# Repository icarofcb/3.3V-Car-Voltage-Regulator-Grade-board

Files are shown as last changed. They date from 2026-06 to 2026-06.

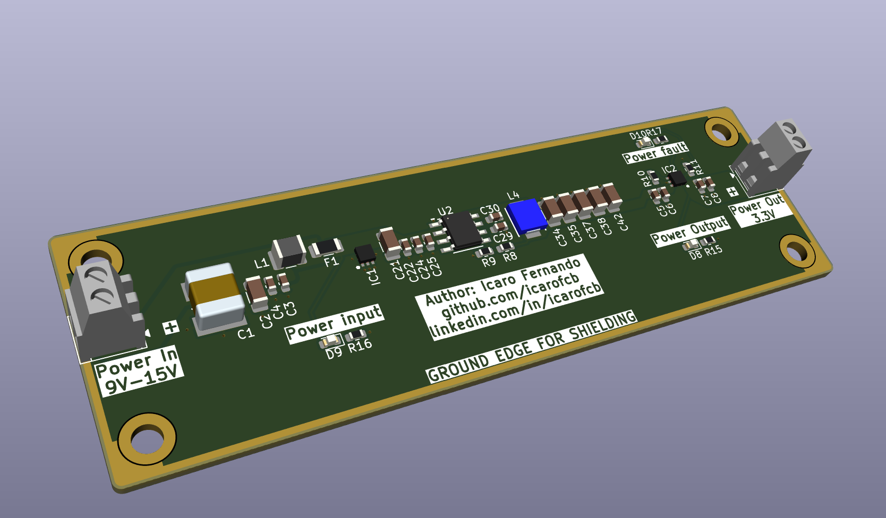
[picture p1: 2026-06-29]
manufacture files/BOARD-1.png

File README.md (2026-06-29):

# 3V3-REGULATOR — Design Notes

**Project:** Automotive-grade 9 V–15 V to 3.3 V / 500 mA power supply
**Author:** Icaro (github.com/icarofcb)
**Tool:** KiCad 10.0.4 · 2-layer PCB
**Rev:** 1 · 2026-06-28

---

## 1. Overview

This board converts an unregulated automotive DC bus (9 V–15 V) into a clean, regulated **3.3 V rail at up to 500 mA**, with the input, the converter, and the load protected end to end. The signal path is:

```
J2 (9–15 V) → [Protected Input: fuse + ferrite + flat-clamp TVS + bulk caps]
            → [Synchronous Buck: LMR33630BDDA @ 1.4 MHz]
            → [Smart Fuse: TPS25200 eFuse, current limit + OV clamp + fault flag]
            → J9 (3.3 V protected output)
```

Visual diagnostics (power-good and fault LEDs) and four mounting holes are provided for integration and bring-up.

---

## 2. Electrical Specifications

| Parameter | Specification | As-designed |
|---|---|---|
| Input voltage | 9 V – 15 V DC | 9 V – 15 V (LMR33630: 3.8 V–36 V) |
| Output voltage | 3.3 V DC | 3.315 V (FB divider 100 k / 43.2 k) |
| Output current | 500 mA max | eFuse limit ≈ 1.43 A typ (margin) |
| Output power | 1.65 W | 1.65 W |
| Topology | Candidate's choice | **Synchronous buck** (justified §3) |
| Switching frequency | — | 1.4 MHz (LMR33630**B**DDA) |
| Estimated efficiency | State | **≈ 86–88 %** @ 12 V, 0.5 A (§5) |
| Target ripple | State | **< 20 mV pk-pk** (est. ~5 mV, §6) |

---

## 3. Topology Selection & Justification

**Chosen: synchronous step-down (buck) converter.**

A linear regulator (LDO) was rejected on thermal grounds. Dropping 12 V → 3.3 V at 0.5 A in a linear pass element dissipates `(12 − 3.3) × 0.5 = 4.35 W`, and at the 15 V corner `(15 − 3.3) × 0.5 = 5.85 W`. That is an efficiency of only 22–28 % and several watts to remove from a small 2-layer board with no dedicated copper plane — not viable.

A synchronous buck reaches ~85–90 % at this operating point, dissipating only a few hundred mW. The **LMR33630BDDA** was selected because it:

- Covers the full input range with wide margin (3.8 V–36 V vs. 9–15 V), tolerating load-dump ride-through above 15 V.
- Integrates both MOSFETs (synchronous), removing the external catch diode and its loss.
- Switches at **1.4 MHz**, which shrinks the inductor (2.2 µH) and output caps and places the switching fundamental above the AM band, easing conducted-EMI compliance.
- Is marketed as an "ultra-low EMI" SIMPLE SWITCHER in an SO PowerPAD package with low parasitic loop inductance.
- Has an internally compensated, peak-current-mode loop — minimal external part count, robust across line/load.

---

## 4. Functional Block Description

### 4.1 Protected Input Stage

| Ref | Part | Role |
|---|---|---|
| F1 | SF-1206HHA1000R-2 | Board input fuse — hard-fault / short protection. Note on schematic: can be replaced by an automotive blade fuse. |
| L1 | Ferrite 26 Ω @ 100 MHz, 10 A | Series element of the input EMI filter (conducted-emissions / di-dt damping). |
| IC1 | TVS1800DRVR | Flat-clamp surge protection (load-dump / ISO 7637-style transients), 18 V standoff. |
| C1 | 47 µF | Bulk input hold-up. |
| C2, C21 | 10 µF 50 V | Buck input decoupling (high-frequency hot-loop caps). |
| C3, C4, C22, C24 | 0.1 µF | Local HF bypass. |
| C29 | 1 µF | Protected-rail decoupling. |

The fuse, ferrite, and bulk/HF caps form a **pi (C–L–C) input filter**: the ferrite blocks the switcher's di/dt from the harness while the caps supply the pulsed input current locally. The TVS1800 shunts surge energy and clamps flat, with an 18 V standoff that sits comfortably above the 15 V input corner.

### 4.2 Buck Regulator

| Ref | Part | Role |
|---|---|---|
| U2 | LMR33630BDDA | 1.4 MHz synchronous buck, 3.8–36 V in, 3 A. |
| L4 | 2.2 µH | Power inductor. |
| R8 / R9 | 100 k / 43.2 k | Feedback divider → V_OUT = 1.0 V × (1 + 100/43.2) = **3.315 V**. |
| C30 | 0.1 µF | Bootstrap (BOOT–SW). |
| C5 / C7 | 1 µF | VCC / local decoupling. |
| C34, C35, C37, C38, C42 | 10 µF 50 V | Output capacitor bank (3.3 V rail). |

The 1.0 V internal reference and the 100 k / 43.2 k divider set 3.315 V (+0.5 %, within tolerance). The output bank is deliberately conservative for low ripple and good transient response; effective capacitance after DC-bias derating is well below the 50 µF nominal but still ample for this load.

### 4.3 Output Smart Fuse (eFuse)

| Ref | Part | Role |
|---|---|---|
| IC2 | TPS25200DRVR | eFuse: adjustable current limit, OV clamp, OVLO, thermal, reverse blocking, fault flag. |
| R11 | 68 k | R_ILIM → current-limit threshold. |
| D8, D9 (blue) | Power-good indicators | Lit on healthy 3.3 V. |
| D10 (red) | Fault indicator | Driven by FAULT (open-drain). |
| R15, R17 (220 Ω), R16 (1 k) | LED / pull-up resistors | |
| J9 | 282834-2 | Protected 3.3 V output. |

`R_ILIM = 68 kΩ` sets a current-limit threshold of **≈ 1.43 A typ** (≈ 1.30 A min / 1.55 A max over tolerance from the datasheet I_OS equations). That sits comfortably above the 500 mA spec and even above a 1 A transient peak, while still cutting off hard on a downstream short. The TPS25200 also provides an output OV **clamp at ~5.4 V** and **OVLO shutoff at 7.6 V V_IN**, so a failed buck high-side FET dumping the raw input onto the 3.3 V rail is disconnected from the load rather than passed through. The open-drain FAULT asserts on over-current, over-temperature, or over-voltage and drives the red LED — no microcontroller required.

---

## 5. Efficiency Estimate

At 12 V → 3.3 V, 0.5 A, the LMR33630 (1.4 MHz variant) operates around **87 %** per its characteristic curves. The series eFuse adds `60 mΩ × 0.5 A = 30 mV` drop → `~0.9 %` loss. Net **≈ 86 %** at nominal.

Trend across the input range (switching loss scales with V_IN):

| V_IN | Est. converter η | Net (incl. eFuse) |
|---|---|---|
| 9 V | ~89 % | ~88 % |
| 12 V | ~87 % | ~86 % |
| 15 V | ~85 % | ~84 % |

Total dissipation at the worst corner is on the order of a few hundred mW, spread across U2's PowerPAD and L4 — manageable on 2 layers with a stitched ground pour and a thermal-via array under the IC.

---

## 6. Ripple Budget

**Inductor ripple current** (`ΔI_L = V_OUT·(V_IN−V_OUT)/(V_IN·L·f_sw)`):

- 12 V: `3.3 × 8.7 / (12 × 2.2µ × 1.4M) ≈ 0.78 A` pk-pk
- 15 V (worst): `≈ 0.84 A` pk-pk
- Peak inductor current at 0.5 A load: `0.5 + 0.42 ≈ 0.92 A` — far below L4 / U2 limits.

**Output voltage ripple** (ceramic bank, ESR negligible, `ΔV ≈ ΔI_L/(8·f_sw·C_OUT)`):

- With ~40 µF effective: `0.84 / (8 × 1.4M × 40µ) ≈ 2 mV` pk-pk.

**Target: < 20 mV pk-pk**; estimated **~5 mV** including ESL/ESR margin. Input ripple is held down by C1/C2/C21 plus the L1 ferrite (pi filter).

---

## 7. Automotive Best Practices

**Protection (layered):**
1. Input hard-fault / short → F1 (replaceable by a blade fuse, coordinated with the vehicle supply).
2. Surge / load-dump transients → TVS1800 flat clamp (18 V standoff, clamps surge below ~25 V — well under the LMR33630 36 V abs-max and the 50 V cap rating).
3. Output over-current / short / OV / reverse → TPS25200 eFuse with auto-recovery and fault flag.
4. Visual go/no-go → power-good (blue) and fault (red) LEDs.

**EMI / EMC:**
- 1.4 MHz fundamental keeps key harmonics out of the AM band.
- Pi input filter (C–ferrite–C) attenuates conducted emissions on the harness.
- Tight switching hot loop and small SW-node copper minimize radiated emissions.
- TVS + bulk caps address surge immunity (IEC 61000-4-5 class) and EFT/ESD on the input.
- Exposed gold perimeter ring bonds PCB ground to the aluminum enclosure (360° chassis bond), extending the shield to the case.

**Power / Signal Integrity:**
- Output cap bank close to the load connector for low rail impedance and good step-load response.
- Feedback divider routed away from the SW node; FB tap taken at the point of regulation.
- Unbroken bottom-layer ground plane as the reference and lowest-impedance return for every net.

**DFM / DFT / DFA:**
- DFM: assembly-friendly 1206/0603 passives, standard footprints, thermal-via arrays under U2 and IC2, generous clearances for a 2-layer process.
- DFT: test points on V_IN, 3.3 V, FAULT, and GND; FAULT net brought out; LEDs give instant powered diagnostics; output on a keyed connector for in-line current measurement.
- DFA: polarized 282834-2 connectors (no reverse mating), consistent passive orientation, four mounting holes (H1–H4) for mechanical fixturing and vibration robustness.

---

## 8. 2-Layer PCB Layout Strategy

The stackup is deliberately simple and EMC-driven: **the top layer carries all signals and power; the bottom layer is an unbroken ground plane.** On a 2-layer board this is the single biggest lever for EMC and integrity — every trace on top runs over continuous reference copper, so each signal's return current flows in the image directly beneath it, giving the smallest possible loop area and a clean, low-impedance return for every net.

- **Solid ground plane (bottom):** the entire second layer is ground, with no splits or cutouts. Nothing signal or power is routed on the bottom, because any trace there would slot the plane and force return current to detour around it (added loop area → radiated emissions and ground bounce).
- **Input hot loop** (C2/C21 → VIN → GND) kept physically tiny on top — it carries the highest di/dt — with its ground return dropped straight into the plane through vias at the cap pads.
- **SW node** copper minimized in area (radiator) but wide enough for current; inductor placed immediately at SW.
- **Returns / stitching:** a ground via at every ground pad ties each device to the plane with minimal inductance; vias along the high-current return path keep impedance low.
- **Chassis-bond shield ring:** an exposed (soldermask-free), gold-finished (ENIG) ground ring runs around the board perimeter and is via-stitched to the bottom plane, so it bonds PCB ground to the aluminum enclosure around the full edge. Gold keeps the contact low-resistance and corrosion-free under compression and vibration (bare copper would oxidize into an unreliable joint). The 360° bond extends the Faraday shield onto the case, improving radiated emissions and immunity, and gives a short chassis return path for ESD/surge.
- **Thermal:** U2 PowerPAD and IC2 EP drop into the bottom ground copper through via arrays, using the full plane as the heat-spreader.
- **Output caps** hugging the inductor output and the eFuse input; protected-rail caps near J9.
- **Sensitive nets** (FB, ILIM) kept short over solid ground, away from SW and the inductor field.
- **Input protection** (F1, L1, TVS1800) placed at the connector edge so transient energy is shunted before it propagates onto the board.

---

## 9. Component Selection Notes

- **Decoupling / bulk MLCCs:** specified as Murata **GCM** series (AEC-Q200, X7R, −55…+125 °C). For positions in 0805 and larger, or anywhere board flex/vibration is a concern, the **GCJ** soft-termination equivalents are the preferred upgrade (conductive-polymer layer that absorbs board-bending stress and prevents flex cracks).
- **10 µF / 50 V / 1206:** only available as **X7T** in this size/voltage (e.g. GCM31CD71H106KE36L) — note the wider temperature/DC-bias characteristic vs. X7R and the heavy DC-bias derating on the 9–15 V input cap (C2).
- **Voltage derating:** 50 V ceramics on a 3.3 V rail and on the 12 V bus keep stress well inside ECSS/IPC-style derating; the 1 µF/0603 parts are 25 V (fine on 3.3 V/5 V nodes, re-evaluate if any sits on the raw 9–15 V bus).
- **eFuse R_ILIM = 68 kΩ** verified against the TPS25200 datasheet I_OS equations (not just the table): min ≈ 1.30 A stays clear of the load; max ≈ 1.55 A gives a defined cut-off.

---

## 10. Submitted Files

| File | Description |
|---|---|
| `3v3-regulator.kicad_pro` | KiCad project |
| `3v3-regulator.kicad_sch` | Schematic |
| `3v3-regulator.kicad_pcb` | 2-layer PCB layout |
| `README` / Design Notes | This document |

## 11. Extra Files

The `manufacture files` directory holds the full output set: design notes, fabrication/manufacturing files, and the schematic export. Gerbers and the schematic source are also available in the `gerber/` and `Schematic/` directories.

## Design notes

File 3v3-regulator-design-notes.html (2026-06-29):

Design Notes · Rev 1 · 2026-06-28

# 3V3-Regulator

Automotive-grade 9 V–15 V → 3.3 V / 500 mA power supply. Synchronous buck with a fully protected input and a smart-fuse output stage. KiCad 10 · 2-layer PCB.

Vin

9–15 V

Vout

3.315 V

Iout

500 mA

Efficiency

≈86 %

Ripple

<20 mV

Title3V3-REGULATOR — Design Notes

SizeA4

Rev1

AuthorIcaro · github.com/icarofcb

ToolKiCad 10.0.4

Id1/1

01

## Overview

This board converts an unregulated automotive DC bus (9 V–15 V) into a clean, regulated 3.3 V rail at up to 500 mA, with the input, the converter, and the load protected end to end. The signal path is:

In

Protected Input

Fuse + ferrite + flat-clamp TVS + bulk caps

Convert

Synchronous Buck

LMR33630BDDA @ 1.4 MHz

Protect

Smart Fuse

TPS25200 eFuse · limit + OV clamp + fault flag

Out

3.3 V Output

Protected rail to J9

Visual diagnostics (power-good and fault LEDs) and four mounting holes are provided for integration and bring-up.

02

## Electrical Specifications

Parameter | Specification | As-designed
Input voltage | 9 V – 15 V DC | 9–15 V (LMR33630: 3.8–36 V)
Output voltage | 3.3 V DC | 3.315 V (FB 100 k / 43.2 k)
Output current | 500 mA max | eFuse limit ≈ 1.43 A typ
Output power | 1.65 W | 1.65 W
Topology | Candidate's choice | Synchronous buck (§3)
Switching frequency | — | 1.4 MHz (LMR33630BDDA)
Estimated efficiency | State | ≈ 86–88 % @ 12 V, 0.5 A
Target ripple | State | < 20 mV pk-pk (est. ~5 mV)

03

## Topology Selection & Justification

Chosen: synchronous step-down (buck) converter.

A linear regulator was rejected on thermal grounds. Dropping 12 V → 3.3 V at 0.5 A in a linear pass element dissipates (12 − 3.3) × 0.5 = 4.35 W, and at the 15 V corner (15 − 3.3) × 0.5 = 5.85 W — an efficiency of only 22–28 % and several watts to remove from a small 2-layer board with no dedicated copper plane. Not viable.

A synchronous buck reaches ~85–90 % at this operating point, dissipating only a few hundred mW. The LMR33630BDDA was selected because it:

- Covers the full input range with wide margin (3.8–36 V vs. 9–15 V), tolerating load-dump ride-through above 15 V.
- Integrates both MOSFETs (synchronous), removing the external catch diode and its loss.
- Switches at 1.4 MHz, shrinking the inductor (2.2 µH) and output caps and placing the fundamental above the AM band for easier conducted-EMI compliance.
- Is an "ultra-low EMI" SIMPLE SWITCHER in an SO PowerPAD package with low parasitic loop inductance.
- Uses an internally compensated, peak-current-mode loop — minimal external parts, robust across line/load.

04

## Functional Block Description

### 4.1 — Protected Input Stage

Ref | Part | Role
F1 | SF-1206HHA1000R-2 | Board input fuse — hard-fault / short protection. Schematic note: replaceable by an automotive blade fuse.
L1 | Ferrite 26 Ω @ 100 MHz, 10 A | Series element of the input EMI filter (conducted emissions / di-dt damping).
IC1 | TVS1800DRVR | Flat-clamp surge protection (load-dump / ISO 7637-style transients), 18 V standoff.
C1 | 47 µF | Bulk input hold-up.
C2, C21 | 10 µF 50 V | Buck input decoupling (HF hot-loop caps).
C3, C4, C22, C24 | 0.1 µF | Local HF bypass.
C29 | 1 µF | Protected-rail decoupling.

The fuse, ferrite, and bulk/HF caps form a pi (C–L–C) input filter: the ferrite blocks the switcher's di/dt from the harness while the caps supply the pulsed input current locally. The TVS1800 shunts surge energy and clamps flat, with an 18 V standoff that sits comfortably above the 15 V input corner.

### 4.2 — Buck Regulator

Ref | Part | Role
U2 | LMR33630BDDA | 1.4 MHz synchronous buck, 3.8–36 V in, 3 A.
L4 | 2.2 µH | Power inductor.
R8 / R9 | 100 k / 43.2 k | Feedback divider → Vout = 1.0 V × (1 + 100/43.2) = 3.315 V.
C30 | 0.1 µF | Bootstrap (BOOT–SW).
C5 / C7 | 1 µF | VCC / local decoupling.
C34/35/37/38/42 | 10 µF 50 V | Output capacitor bank (3.3 V rail).

The 1.0 V internal reference and the 100 k / 43.2 k divider set 3.315 V (+0.5 %, within tolerance). The output bank is deliberately conservative for low ripple and good transient response; effective capacitance after DC-bias derating is well below the 50 µF nominal but still ample for this load.

### 4.3 — Output Smart Fuse (eFuse)

Ref | Part | Role
IC2 | TPS25200DRVR | eFuse: adjustable current limit, OV clamp, OVLO, thermal, reverse blocking, fault flag.
R11 | 68 k | RILIM → current-limit threshold.
D8, D9 (blue) | Power-good | Lit on healthy 3.3 V.
D10 (red) | Fault | Driven by FAULT (open-drain).
R15/R17 220Ω · R16 1k | LED / pull-up | Indicator drive.
J9 | 282834-2 | Protected 3.3 V output.

R_ILIM = 68 kΩ sets a current-limit threshold of ≈ 1.43 A typ (≈ 1.30 A min / 1.55 A max over tolerance, from the datasheet IOS equations). That sits comfortably above the 500 mA spec and even above a 1 A transient peak, while still cutting off hard on a downstream short. The TPS25200 also provides an output OV clamp at ~5.4 V and OVLO shutoff at 7.6 V Vin, so a failed buck high-side FET dumping the raw input onto the 3.3 V rail is disconnected from the load rather than passed through. The open-drain FAULT asserts on over-current, over-temperature, or over-voltage and drives the red LED — no microcontroller required.

05

## Efficiency Estimate

At 12 V → 3.3 V, 0.5 A, the LMR33630 (1.4 MHz variant) operates around 87 % per its characteristic curves. The series eFuse adds 60 mΩ × 0.5 A = 30 mV drop → ~0.9 % loss. Net ≈ 86 % at nominal.

Vin | Est. converter η | Net (incl. eFuse)
9 V | ~89 % | ~88 %
12 V | ~87 % | ~86 %
15 V | ~85 % | ~84 %

Total dissipation at the worst corner is on the order of a few hundred mW, spread across U2's PowerPAD and L4 — manageable on 2 layers with a stitched ground pour and a thermal-via array under the IC.

06

## Ripple Budget

Inductor ripple current ΔI_L = V_OUT·(V_IN−V_OUT) / (V_IN·L·f_sw)

- 12 V: 3.3 × 8.7 / (12 × 2.2µ × 1.4M) ≈ 0.78 A pk-pk
- 15 V (worst): ≈ 0.84 A pk-pk
- Peak inductor current at 0.5 A load: 0.5 + 0.42 ≈ 0.92 A — far below L4 / U2 limits.

Output voltage ripple (ceramic bank, ESR negligible) ΔV ≈ ΔI_L / (8·f_sw·C_OUT)

- With ~40 µF effective: 0.84 / (8 × 1.4M × 40µ) ≈ 2 mV pk-pk.

Target: < 20 mV pk-pk; estimated ~5 mV including ESL/ESR margin. Input ripple is held down by C1/C2/C21 plus the L1 ferrite (pi filter).

07

## Automotive Best Practices

### Protection (layered)

1. Input hard-fault / short → F1 (replaceable by a blade fuse, coordinated with the vehicle supply).
2. Surge / load-dump transients → TVS1800 flat clamp (18 V standoff, clamps surge below ~25 V — well under the LMR33630 36 V abs-max and the 50 V cap rating).
3. Output over-current / short / OV / reverse → TPS25200 eFuse with auto-recovery and fault flag.
4. Visual go/no-go → power-good (blue) and fault (red) LEDs.

### EMI / EMC

- 1.4 MHz fundamental keeps key harmonics out of the AM band.
- Pi input filter (C–ferrite–C) attenuates conducted emissions on the harness.
- Tight switching hot loop and small SW-node copper minimize radiated emissions.
- TVS + bulk caps address surge immunity (IEC 61000-4-5 class) and EFT/ESD on the input.
- Exposed gold perimeter ring bonds PCB ground to the aluminum enclosure (360° chassis bond), extending the shield to the case.

### Power / Signal Integrity

- Output cap bank close to the load connector for low rail impedance and good step-load response.
- Feedback divider routed away from the SW node; FB tap taken at the point of regulation.
- Unbroken bottom-layer ground plane as the reference and lowest-impedance return for every net.

### DFM / DFT / DFA

- DFM: assembly-friendly 1206/0603 passives, standard footprints, thermal-via arrays under U2 and IC2, generous clearances for a 2-layer process.
- DFT: test points on Vin, 3.3 V, FAULT, and GND; FAULT net brought out; LEDs give instant powered diagnostics; output on a keyed connector for in-line current measurement.
- DFA: polarized 282834-2 connectors (no reverse mating), consistent passive orientation, four mounting holes (H1–H4) for fixturing and vibration robustness.

08

## 2-Layer PCB Layout Strategy

The stackup is deliberately simple and EMC-driven: the top layer carries all signals and power; the bottom layer is an unbroken ground plane. On a 2-layer board this is the single biggest lever for EMC and integrity — every trace on top runs over continuous reference copper, so each signal's return current flows in the image directly beneath it, giving the smallest possible loop area and a clean, low-impedance return for every net.

- Solid ground plane (bottom): the entire second layer is ground, with no splits or cutouts. Nothing signal or power is routed on the bottom, because any trace there would slot the plane and force return current to detour around it (loop area → radiated emissions and ground bounce).
- Input hot loop (C2/C21 → VIN → GND) kept physically tiny on top — it carries the highest di/dt — with its ground return dropped straight into the plane through vias at the cap pads.
- SW node copper minimized in area (radiator) but wide enough for current; inductor placed immediately at SW.
- Returns / stitching: a ground via at every ground pad ties each device to the plane with minimal inductance; vias along the high-current return path keep impedance low.
- Chassis-bond shield ring: an exposed (soldermask-free), gold-finished (ENIG) ground ring runs around the board perimeter and is via-stitched to the bottom plane, bonding PCB ground to the aluminum enclosure around the full edge. Gold keeps the contact low-resistance and corrosion-free under compression and vibration (bare copper would oxidize into an unreliable joint). The 360° bond extends the Faraday shield onto the case — better radiated emissions and immunity — and gives a short chassis return for ESD/surge.
- Thermal: U2 PowerPAD and IC2 EP drop into the bottom ground copper through via arrays, using the full plane as the heat-spreader.
- Output caps hugging the inductor output and the eFuse input; protected-rail caps near J9.
- Sensitive nets (FB, ILIM) kept short over solid ground, away from SW and the inductor field.
- Input protection (F1, L1, TVS1800) at the connector edge so transient energy is shunted before it propagates onto the board.

09

## Component Selection Notes

- Decoupling / bulk MLCCs: Murata GCM series (AEC-Q200, X7R, −55…+125 °C). For positions in 0805 and larger, or anywhere board flex/vibration is a concern, the GCJ soft-termination equivalents are the preferred upgrade — a conductive-polymer layer that absorbs board-bending stress and prevents flex cracks.
- 10 µF / 50 V / 1206: only available as X7T at this size/voltage (e.g. GCM31CD71H106KE36L) — note the wider temperature/DC-bias characteristic vs. X7R and the heavy DC-bias derating on the 9–15 V input cap (C2).
- Voltage derating: 50 V ceramics on a 3.3 V rail and on the 12 V bus keep stress well inside ECSS/IPC-style derating; the 1 µF/0603 parts are 25 V (fine on 3.3 V/5 V nodes — re-evaluate if any sits on the raw 9–15 V bus).
- eFuse RILIM = 68 kΩ verified against the TPS25200 datasheet IOS equations (not just the table): min ≈ 1.30 A stays clear of the load; max ≈ 1.55 A gives a defined cut-off.

10

## Submitted Files

File | Description
3v3-regulator.kicad_pro | KiCad project
3v3-regulator.kicad_sch | Schematic
3v3-regulator.kicad_pcb | 2-layer PCB layout
Design Notes | This document

3V3-REGULATOR · Rev 1 · 2026-06-28 Icaro · github.com/icarofcb

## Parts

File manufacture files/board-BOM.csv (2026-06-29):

Reference | Qty | Value | Footprint | MPN | Manufacturer
C1 | 1 | 47uF | CKG57KX7R1E476M335JJ:CAPC6050X350N | KRM55WR71H476MH13K | Murata Electronics
C2,C21,C34,C35,C37,C38,C42 | 7 | 10uF 50V | Capacitor_SMD:C_1206_3216Metric | GCM31CD71H106KE36L | Murata Electronics
C3,C4,C6,C8,C22,C24,C25,C30 | 8 | 0.1 uF | Capacitor_SMD:C_0603_1608Metric | GCM188R71H104KA57D | Murata Electronics
C5,C7,C29 | 3 | 1uF | Capacitor_SMD:C_0603_1608Metric | GCM188R71E105KA64D | Murata Electronics
D8,D9 | 2 | LED-BLUE | LED_SMD:LED_0603_1608Metric | 599-0090-137F | Dialight
D10 | 1 | LED-RED | LED_SMD:LED_0603_1608Metric | 599-0010-137F | Dialight
F1 | 1 | SF-1206HHA1000R-2 | Fuse:Fuse_1206_3216Metric | SF-1206HHA1000R-2 | Bourns
IC1 | 1 | TVS1800DRVR | SON65P200X200X80-7N | TVS1800DRVR | Texas Instruments
IC2 | 1 | TPS25200DRVR | TPS25200DRVR:SON65P200X200X80-7N | TPS25200DRVR | Texas Instruments
J2,J9 | 2 | 282834-2 | TerminalBlock_TE-Connectivity:TerminalBlock_TE_282834-2_1x02_P2.54mm_Horizontal | 282834-2 | TE Connectivity
L1 | 1 | 26R/10A | Inductor_SMD:L_1210_3225Metric | BLE32PN260SH1L | Murata Electronics
L4 | 1 | 2.2uH | SRP4012TA-2R2M:INDPM4441X120N | SRP4012TA-2R2M | Bourns
R8,R10 | 2 | 100k | Resistor_SMD:R_0603_1608Metric | AA0603FR-07100KL | YAGEO
R9 | 1 | 43k2 | Resistor_SMD:R_0603_1608Metric | ERA-3AEB4322V | Panasonic
R11 | 1 | 68k | Resistor_SMD:R_0603_1608Metric | ERA-3AEB683V | Panasonic
R15,R17 | 2 | 220R | Resistor_SMD:R_0603_1608Metric | AC0603FR-07220RL | YAGEO
R16 | 1 | 1kR | Resistor_SMD:R_0603_1608Metric | AA0603FR-071KL | YAGEO
U2 | 1 | LMR33630BDDA | Package_SO:Texas_HSOP-8-1EP_3.9x4.9mm_P1.27mm_ThermalVias | LMR33630BDDA | Texas Instruments

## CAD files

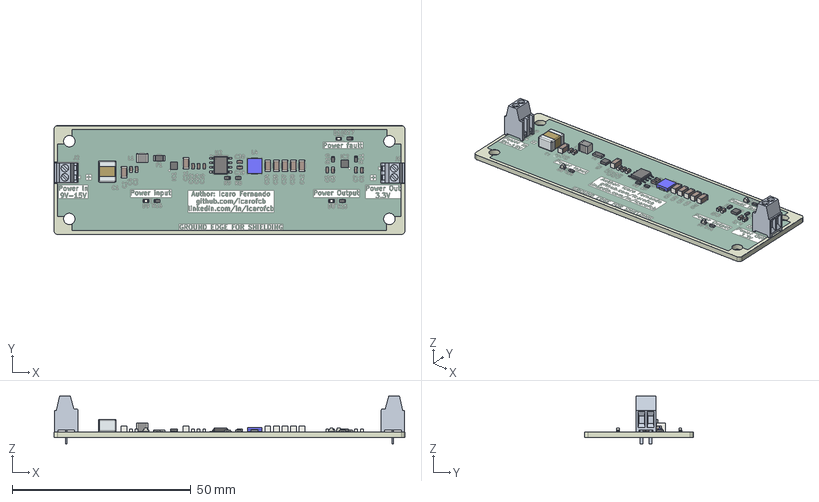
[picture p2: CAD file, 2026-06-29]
manufacture files/board-3d.stp
98.1 x 30.4 x 13.4 mm
R_0603_1608Metric x 7
FilletPin1
FilletPin2
C-282834-2 x 2
L_1210_3225Metric
C_0603_1608Metric x 11
LED_0603_1608Metric x 3
C_1206_3216Metric x 7
HTSOP-8-1EP_3.9x4.9mm_P1.27mm_EP2.4x3.2mm
BODY-SON x 2
PIN1-ID x 2
Fuse_1206_3216Metric
3v3-regulator_silkscreen
3v3-regulator_soldermask x 2
3v3-regulator_PCB

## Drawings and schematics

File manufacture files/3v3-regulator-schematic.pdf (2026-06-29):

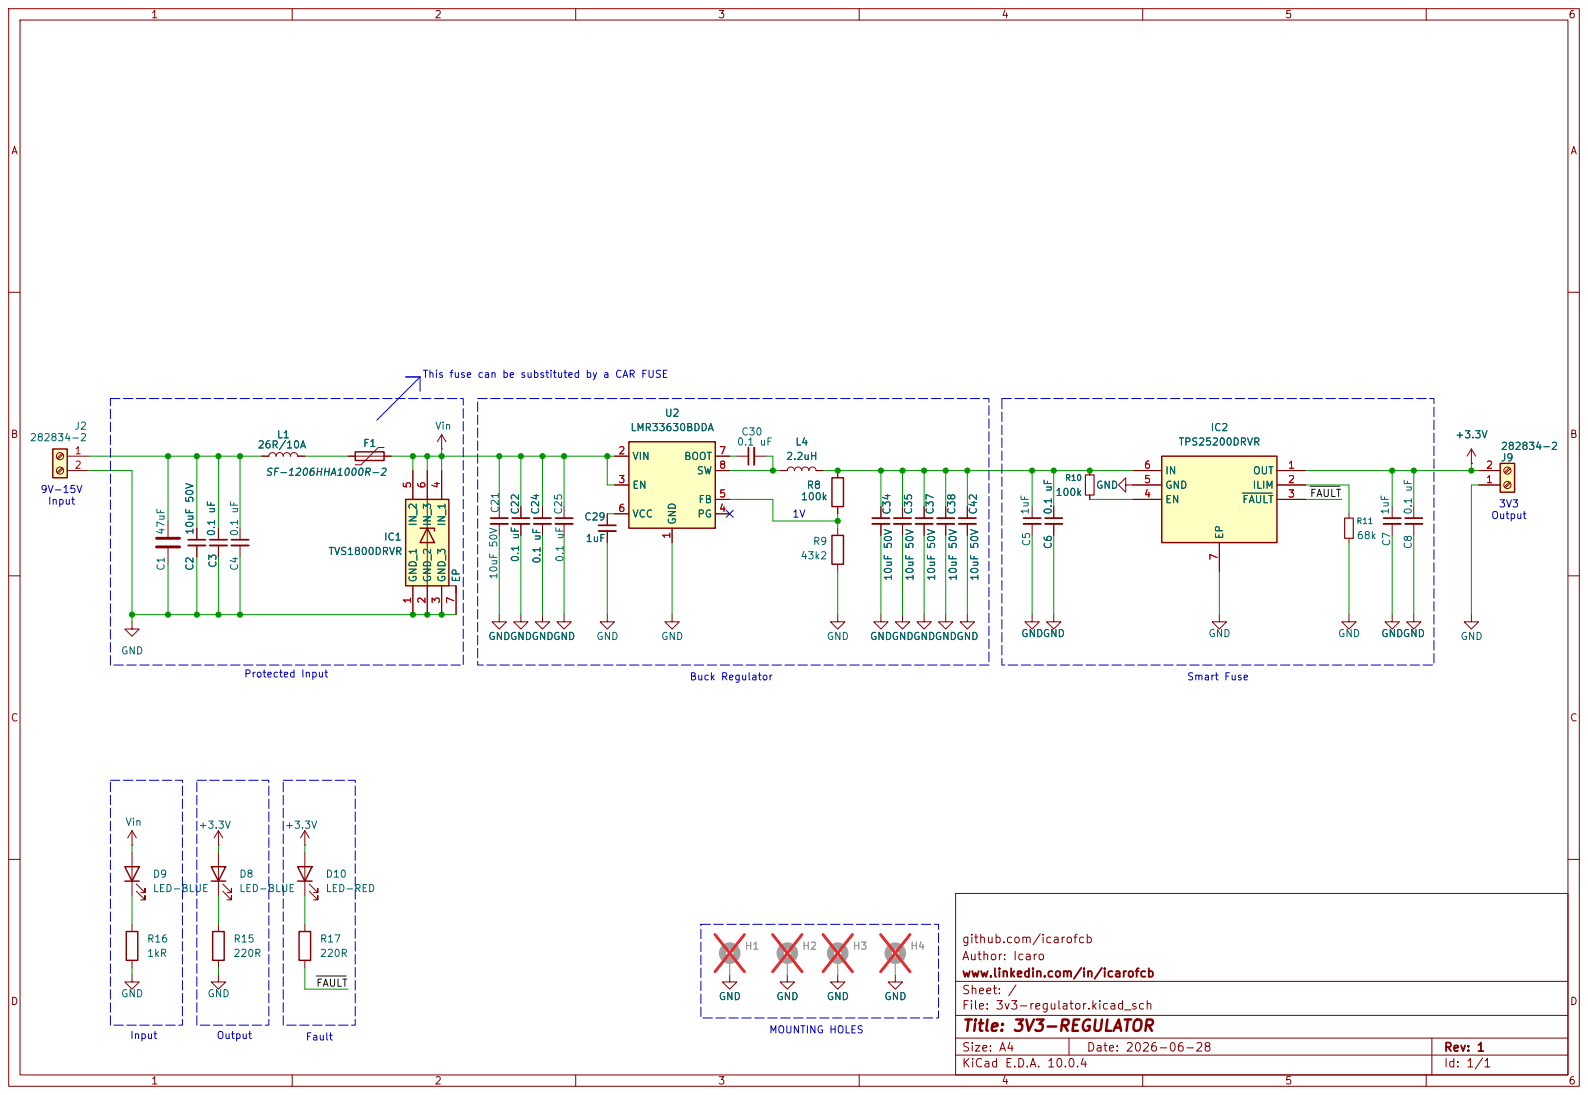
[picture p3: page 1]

7 GND H2 GND GND H1 GND GND H3 H4

Author: Icaro
www.linkedin.com/in/icarofcb
Sheet: /
File: 3v3-regulator.kicad_sch
Title: 3V3-REGULATOR

Size: A4 | Rev: 1
KiCad E.D.A. 10.0.4 | Id: 1/1

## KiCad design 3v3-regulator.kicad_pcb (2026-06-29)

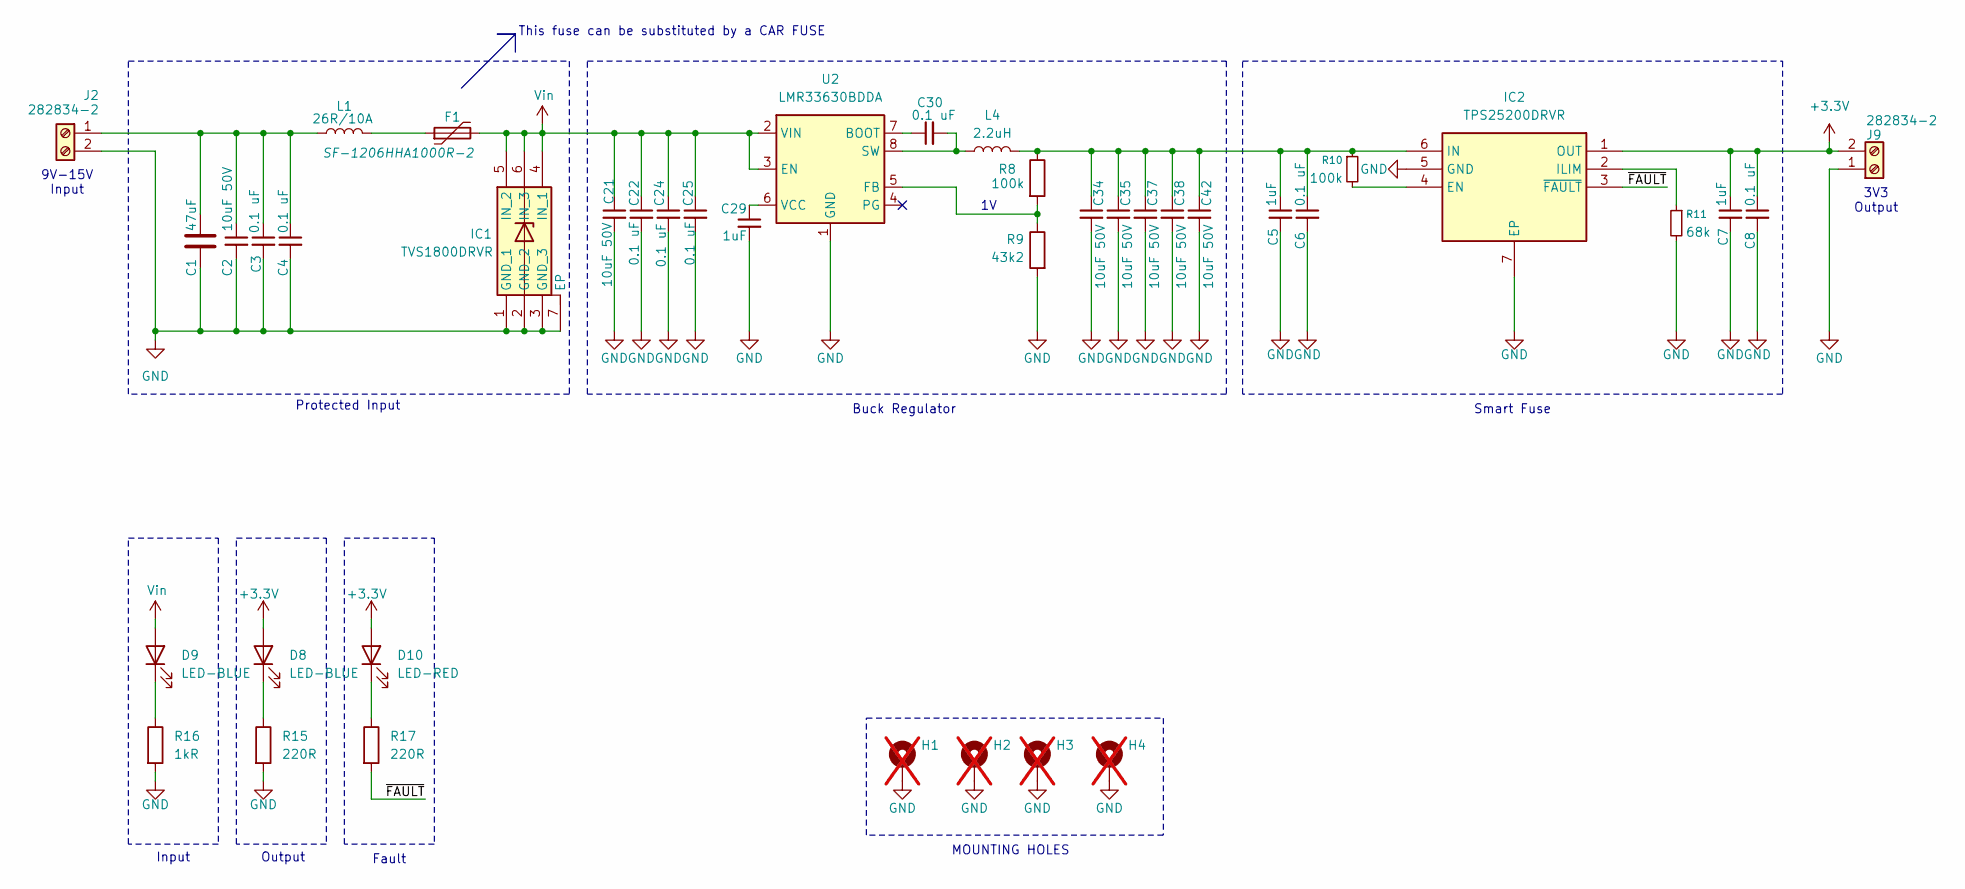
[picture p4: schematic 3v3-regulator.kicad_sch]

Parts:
C1: 47uF; CAPC6050X350N; MPN KRM55WR71H476MH13K; Digi-Key_PN 445-174690-6-ND
C2, C21, C34, C35, C37, C38, C42: 10uF 50V; C_1206_3216Metric; MPN GCM31CD71H106KE36L; LCSC-PN C13585
C3, C4, C6, C8, C22, C24, C25, C30: 0.1 uF; C_0603_1608Metric; MPN GCM188R71H104KA57D; LCSC-PN C106256
C5, C7: 1uF; C_0603_1608Metric; MPN GCM188R71E105KA64D
C29: 1uF; C_0603_1608Metric; MPN GCM188R71E105KA64D; Digi-Key_PN 490-13409-6-ND
D8, D9: LED-BLUE; LED_0603_1608Metric; MPN 599-0090-137F
D10: LED-RED; LED_0603_1608Metric; MPN 599-0010-137F
F1: SF-1206HHA1000R-2; Fuse_1206_3216Metric; MPN SF-1206HHA1000R-2; Mouser Part Number 652-SF-1206HHA1000R2
H1, H2, H3, H4: MountingHole_Pad; MountingHole_3.2mm_M3_DIN965_Pad; not fitted
IC1: TVS1800DRVR; SON65P200X200X80-7N; MPN TVS1800DRVR
IC2: TPS25200DRVR; SON65P200X200X80-7N; Mouser Part Number 595-TPS25200DRVR
J2, J9: 282834-2; TerminalBlock_TE_282834-2_1x02_P2.54mm_Horizontal; MPN 282834-2
L1: 26R/10A; L_1210_3225Metric; MPN BLE32PN260SH1L; Mouser Part Number 81-BLE32PN260SH1L
L4: 2.2uH; INDPM4441X120N; MPN SRP4012TA-2R2M; Mouser Part Number 652-SRP4012TA-2R2M
R8: 100k; R_0603_1608Metric; MPN AA0603FR-07100KL; LCSC-PN C25741
R9: 43k2; R_0603_1608Metric; MPN ERA-3AEB4322V; Mouser Part Number 667-ERA-3AEB4322V
R10: 100k; R_0603_1608Metric; MPN AA0603FR-07100KL
R11: 68k; R_0603_1608Metric; MPN ERA-3AEB683V
R15, R17: 220R; R_0603_1608Metric; MPN AC0603FR-07220RL
R16: 1kR; R_0603_1608Metric; MPN AA0603FR-071KL
U2: LMR33630BDDA; Texas_HSOP-8-1EP_3.9x4.9mm_P1.27mm_ThermalVias; MPN LMR33630BDDA; Mouser Part Number 595-LMR33630BDDA

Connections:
+3.3V: C7.1, C8.1, D8.2 (A), D10.2 (A), IC2.1 (OUT), J9.2
/~FAULT: IC2.3 (~FAULT), R17.2
GND: C1.2, C2.2, C3.2, C4.2, C5.2, C6.2, C7.2, C8.2, C21.2, C22.2, C24.2, C25.2, C29.2, C34.2, C35.2, C37.2, C38.2, C42.2, H1.1 (1_1), H2.1 (1_1), H3.1 (1_1), H4.1 (1_1), IC1.1 (GND_1), IC1.2 (GND_2), IC1.3 (GND_3), IC1.7 (EP), IC2.5 (GND), IC2.7 (EP), J2.2, J9.1, R9.2, R11.2, R15.2, R16.2, U2.1 (GND), U2.9 (GND)
unnamed: D8.1 (K), R15.1
unnamed: D9.1 (K), R16.1
unnamed: D10.1 (K), R17.1
unnamed: F1.1, L1.2
unnamed: IC2.4 (EN), R10.2
unnamed: IC2.2 (ILIM), R11.1
unnamed: C5.1, C6.1, C34.1, C35.1, C37.1, C38.1, C42.1, IC2.6 (IN), L4.2, R8.1, R10.1
unnamed: C1.1, C2.1, C3.1, C4.1, J2.1, L1.1
unnamed: C30.1, U2.7 (BOOT)
unnamed: R8.2, R9.1, U2.5 (FB)
unnamed: C30.2, L4.1, U2.8 (SW)
unnamed: C29.1, U2.6 (VCC)
Vin: C21.1, C22.1, C24.1, C25.1, D9.2 (A), F1.2, IC1.4 (IN_1), IC1.5 (IN_2), IC1.6 (IN_3), U2.2 (VIN), U2.3 (EN)

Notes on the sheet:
MOUNTING HOLES
Buck Regulator
Input
Fault
This fuse can be substituted by a CAR FUSE
Output
9V-15V Input
3V3 Output
Protected Input
Smart Fuse

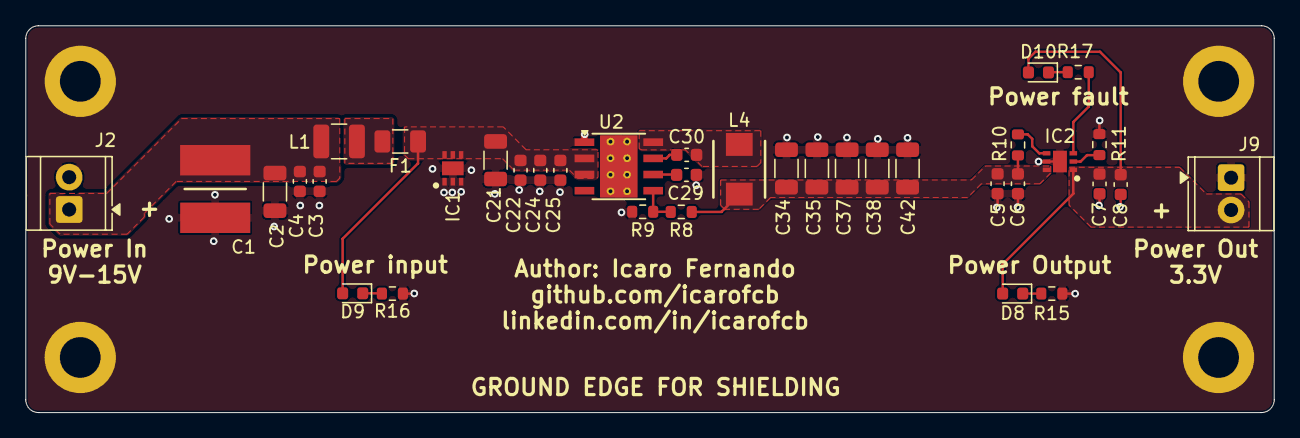
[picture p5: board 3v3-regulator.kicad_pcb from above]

Board: 2 copper layers, 98.1 x 30.4 mm, 41 parts (0 on the bottom side), 16 nets.

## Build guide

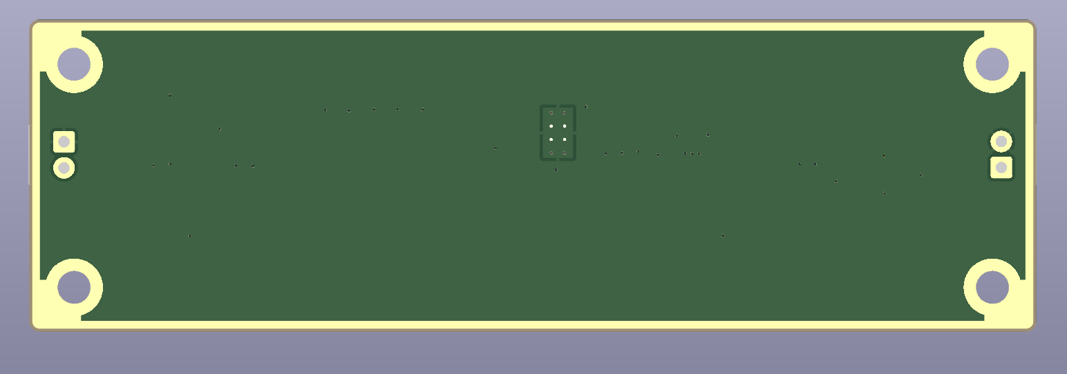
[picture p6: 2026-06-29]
manufacture files/BOARD-BOT.png

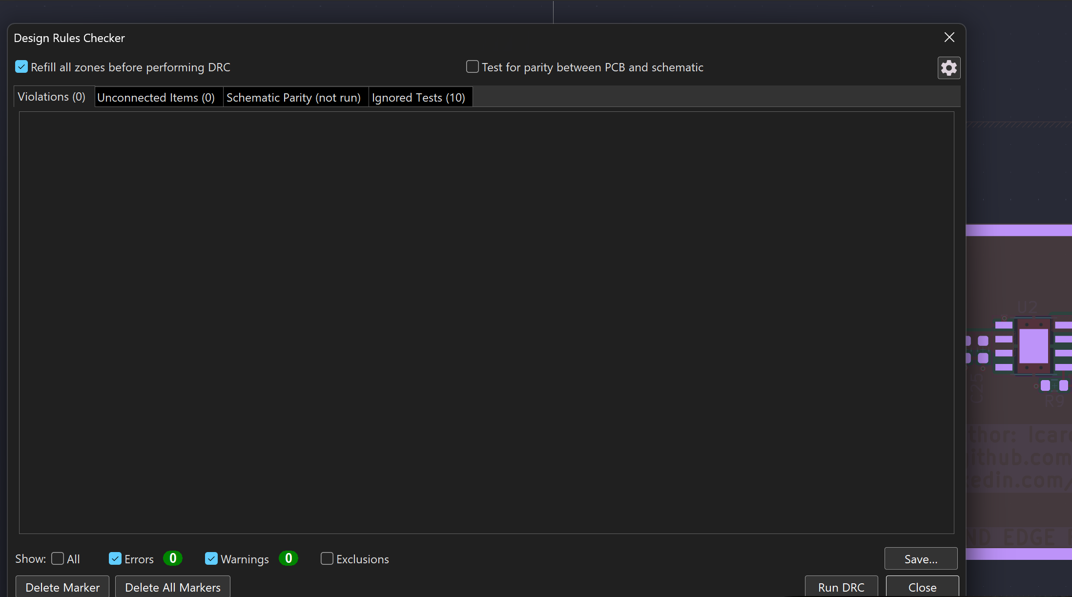
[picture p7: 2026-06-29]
manufacture files/DRC-ERROR-CHECK.png

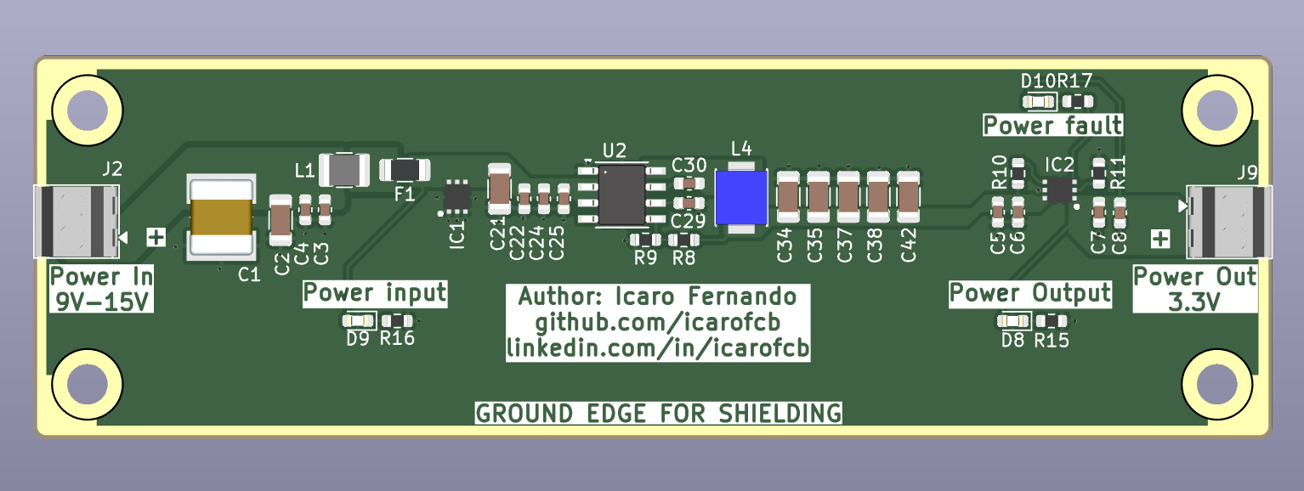
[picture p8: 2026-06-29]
manufacture files/BOARD-TOP.png
